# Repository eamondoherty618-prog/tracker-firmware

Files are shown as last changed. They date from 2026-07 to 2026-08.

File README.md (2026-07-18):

# 123 Mobile Track

Firmware, recovery tools, and deployment helpers for the tracker hardware
behind `123 Mobile Track`.

Current firmware: `v0.11.1`

## Start here

- [Build one tracker](docs/build-one-tracker.md)
- [Project map](docs/project-map.md)
- [Hardware wiring](docs/hardware-wiring.md)
- [Deployment guide](DEPLOYMENT.md)

## What is in this repo

| Path | What it is |
|---|---|
| `src/`, `include/`, `platformio.ini` | Tracker firmware. |
| `flash_new_tracker.sh` | Flash a brand-new board over USB and log its ID. |
| `make_sd_card.sh` | Build a field-recovery microSD card. |
| `deploy_firmware.sh` | Build and publish an OTA firmware release. |
| `fleet_inventory.csv` | Flash log for boards that have been provisioned. |
| `hardware/obd_tracker_carrier_v1/` | KiCad carrier-board files, BOM, placement file, and mechanical references. |
| `docs/` | Plain-English build guide, diagrams, wiring, and system overview. |

## Quick build and flash

```sh
pio run
pio run -t upload
./flash_new_tracker.sh
./make_sd_card.sh /Volumes/YOURCARD
```

## How the system fits together

1. The tracker boots on a `LilyGo T-SIM7000G`.
2. It reads GPS and optional add-ons like CAN/OBD2 or the impact sensor.
3. It sends telemetry to `123mobiletrack.com`.
4. The app and dashboard show the live vehicle state.
5. OTA releases are published from this repo and pulled by the trackers on
   their next check-in.

If you need the wiring details or the install order, start with the build guide
above.

## Repo hygiene

Tracked files should be firmware, deployment scripts, docs, and hardware source
files. Generated outputs, local KiCad session files, zip packages, telemetry
logs, PlatformIO builds, and unrelated shop/design files are ignored.

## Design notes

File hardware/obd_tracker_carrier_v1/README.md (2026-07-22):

# OBD Tracker Carrier Board v1

This package is a v1 KiCad-oriented carrier design for the proven LilyGo
T-SIM7000G + CAN + ADXL375 vehicle tracker architecture.

## Architecture Decision

Use **Option A** for v1: a carrier board for the proven LilyGo T-SIM7000G module.
The LilyGo already integrates the ESP32-WROVER, SIM7000G, USB flashing, SIM,
GNSS/LTE RF, battery charging, and antennas. Keeping it as a replaceable module
cuts RF/layout risk and small-batch cost. A fully native ESP32/SIM7000G board is
the right v2 only after fleet field data proves the enclosure, power section,
and harness approach.

## Board Geometry

- Board: **88.0 x 40.0 mm**, 1.6 mm FR-4. The KiCad source is a 2-layer v1 scaffold; a 4-layer production finalization is recommended for better EMI and thermal margin.
- Mounting holes: M2.5 clearance, 2.7 mm drill, 5.6 mm copper keepout.
- Hole centers:
  - H1: (4.0, 4.0) mm
  - H2: (84.0, 4.0) mm
  - H3: (84.0, 36.0) mm
  - H4: (4.0, 36.0) mm
- LilyGo module envelope: 66.0 x 27.0 mm at lower-left coordinate (18.0, 6.5) mm.
- Optional bottom 18650 holder envelope: 76.0 x 21.0 mm at lower-left coordinate (8.0, 9.5) mm.

The DXF contains the exact outline, hole centers, LilyGo envelope, and 18650
alternate footprint. The STEP file is a simplified board envelope for enclosure
blocking; use the DXF for exact hole cutouts.

## Functional Nets

- OBD2 input: J1 pin 1 = OBD16 +12V, pin 2 = OBD4 GND, pin 3 = OBD6 CAN-H, pin 4 = OBD14 CAN-L.
- CAN transceiver: TJA1051T/3 or equivalent, TXD -> GPIO32, RXD -> GPIO33, VCC = 5V, VIO = 3.3V.
- ADXL375: SDA -> GPIO21, SCL -> GPIO22, INT1 -> GPIO34, CS high, SDO low for address 0x53.
- Vehicle ADC: protected VIN through 100k/20k divider and 100nF filter to GPIO35.
- Battery ADC: VBAT through 1M/1M divider and 100nF filter to GPIO36.
- Status LED: GPIO23 active high, optional.
- Reserved LilyGo pins: GPIO26/27 modem UART and GPIO2/13/14/15 SD remain unconnected.

## Power Section

The v1 power path is:

`OBD +12V -> F1 resettable fuse -> D2 SMBJ33A TVS -> D1 5A reverse Schottky -> TPS54360 60V buck -> +5V`

The +5V rail feeds the LilyGo VIN/charger path and the 5V CAN transceiver. The
carrier uses the LilyGo's onboard 3.3V regulator and charge circuit. Battery
support is either J2 JST-PH LiPo or BT1 bottom-side 18650 holder, populated per
build, routed to the LilyGo battery/charger pins.

## Build Notes

- DNP R10/JP1 for normal vehicle installs. Only populate 120 ohm termination for bench setups or isolated test harnesses.
- L2 CAN common-mode choke is optional. Populate a CAN choke or 0-ohm bypass links after EMI testing.
- The generated routing scaffold uses bottom-layer orthogonal routes for bottom-side SMD circuitry, including CAN, TPS54360 support nets, ADXL375 I2C/INT, and ADC dividers.
- Use short, twisted OBD harness conductors for CAN-H/CAN-L and keep the harness shield/return strategy consistent with the enclosure.
- Place the ADXL375 side of the board against a rigid standoff area; avoid foam tape directly under the accelerometer if impact fidelity matters.
- Verify the exact LilyGo T-SIM7000G board revision and header geometry before fab. This reference uses the user-supplied 66 x 27 mm target envelope.
- For the lowest-height build, DNP BT1 and use a flat LiPo pouch via J2.

## Files

- `obd_tracker_carrier_v1.kicad_pro` - KiCad project settings and net classes.
- `obd_tracker_carrier_v1.kicad_pcb` - PCB outline, footprints, placement, pad nets, and baseline routing scaffold.
- `obd_tracker_carrier_v1.kicad_sch` - top-level schematic notes in KiCad format.
- `obd_tracker_carrier_v1_legacy.sch` - legacy KiCad schematic notes fallback.
- `bom/obd_tracker_carrier_v1_bom.csv` - BOM with suggested MPNs and LCSC/JLCPCB fields to verify at order time.
- `bom/obd_tracker_carrier_v1_netlist.csv` - readable netlist.
- `fab/obd_tracker_carrier_v1_placement.csv` - placement/mechanical coordinate table.
- `fab/obd_tracker_carrier_v1_stats.rpt` - KiCad-generated board statistics, created by the validation/export pass.
- `fab/obd_tracker_carrier_v1_erc.rpt` - KiCad schematic ERC report, created by the validation/export pass.
- `fab/VALIDATION.md` - validation commands and DRC limitation note.
- `mechanical/obd_tracker_carrier_v1_outline.dxf` - exact 2D board outline/hole/envelope DXF.
- `mechanical/obd_tracker_carrier_v1_board_reference.step` - simplified board envelope STEP.
- `mechanical/obd_tracker_carrier_v1_kicad_board.step` - KiCad-generated board-only STEP, created by the validation/export pass.
- `mechanical/kicad_dxf/` - KiCad-generated DXF exports for Edge.Cuts, Dwgs.User, and B.Fab.

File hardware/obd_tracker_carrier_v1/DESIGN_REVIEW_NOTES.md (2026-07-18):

# Design Review Notes

## Automotive Robustness

- The regulator is intentionally a 60V-class TPS54360 design instead of a cheaper
  24-28V buck module. This gives real headroom for load-dump-like pulses when
  paired with the fuse and SMBJ33A TVS.
- A Schottky reverse-protection diode is used for v1 simplicity and low sourcing
  risk. If bench thermal testing shows too much dissipation during long cellular
  upload bursts, replace D1 with an automotive high-side ideal-diode PFET circuit.
- The v1 buck should be validated with an electronic load using at least 2A pulses
  on +5V and with cranking sag profiles. The Li-ion backup should bridge crank
  intervals where the 5V buck falls out of regulation.

## Layout Risks To Verify In KiCad

- Run KiCad DRC after binding the exact vendor footprints.
- Review the TPS54360 compensation and switching loop against the TI datasheet.
- Keep the buck hot loop small: U2 VIN/GND, D3, and input capacitors should be
  tightened during final layout pass.
- Confirm the LilyGo module's USB-C remains accessible through the enclosure
  service opening or removable lid.
- Confirm ADXL375 orientation against firmware before using axis data for anything
  beyond magnitude-based impact detection.

## Fabrication Defaults

- KiCad source is a 2-layer v1 scaffold so it opens cleanly in KiCad 10. For
  production, convert to 4 layers: F.Cu signal/power, In1 GND plane, In2 +5V/VBAT
  pours, B.Cu signal/power.
- 1 oz outer copper is acceptable for a bench v1, but 2 oz outer copper improves reverse
  diode and buck thermal margin.
- ENIG finish preferred for corrosion resistance in a sealed but vehicle-mounted enclosure.

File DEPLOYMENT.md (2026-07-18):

# Deploying Trackers

Use this guide when you are setting up a new tracker, recovering a tracker in
the field, or wiring optional add-on hardware.

For a printable start-to-finish shop guide with diagrams, start with
[Build one tracker](docs/build-one-tracker.md).

If you just want the wiring and pinout, start with
[Hardware wiring](docs/hardware-wiring.md). If you want the overall system
flow, start with [Project map](docs/project-map.md).

## 1. Bench flash a new board

Use the factory image for every brand-new board.

```sh
./flash_new_tracker.sh
```

What happens:

- The board gets the same generic factory firmware.
- It names itself from the last six hex digits of its efuse MAC.
- The ID is logged to `fleet_inventory.csv`.
- The tracker advertises over BLE so the mobile app can claim it.

After flashing:

- Unplug and replug the board once.
- Put the printed ID on the case.
- Insert the SIM and power it in the vehicle.

## 2. Adopt it in the app

In the mobile app:

1. Open `Devices`.
2. Tap `Add Device`.
3. Claim the tracker that matches the label on the case.
4. Assign it to a vehicle.

After adoption:

- The tracker stops advertising continuously.
- It only advertises while the vehicle is on a trip.
- The dashboard starts showing live state for that vehicle.

## 3. Recover a unit with microSD

If the board is already running firmware `>= v0.10.5`, use the recovery card.

```sh
./make_sd_card.sh /Volumes/YOURCARD
```

Then:

1. Eject the card.
2. Insert it into the tracker.
3. Power-cycle the tracker.

The tracker checks the card at boot, verifies the MD5, flashes the new image,
and reboots. Identity in NVS is preserved, so the unit keeps its existing ID.

## 4. Publish an OTA release

```sh
./deploy_firmware.sh
```

This builds the firmware, uploads the binary to the OTA store, and updates the
release metadata. Devices pick it up on the next check-in.

## 5. Optional add-on hardware

See [Hardware wiring](docs/hardware-wiring.md) for the exact pins and safety
notes.

Short version:

- CAN / OBD2 uses `GPIO 32` and `GPIO 33`.
- The accelerometer uses I2C on `GPIO 21` and `GPIO 22`.
- `GPIO 34` is reserved for the accelerometer interrupt line.

## 6. Batch checklist

- [ ] Boards, SIMs, cases, labels
- [ ] One factory flash per new board
- [ ] `fleet_inventory.csv` updated
- [ ] SIMs inserted and active
- [ ] Vehicle install verified on the map
- [ ] Optional CAN / accelerometer wiring checked against the wiring doc

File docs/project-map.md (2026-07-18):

# Project Map

This repository is the firmware and deployment side of `123 Mobile Track`.
It does not contain the full web app source. The live dashboard and API are
hosted at `123mobiletrack.com`, and the firmware talks to that backend over
cellular.

## One-minute overview

System flow

## What lives where

| Piece | Where it lives | What it does |
|---|---|---|
| Firmware | `src/`, `include/`, `platformio.ini` | Runs on the tracker, reads sensors, talks to the modem, and posts telemetry. |
| Hardware carrier | `hardware/obd_tracker_carrier_v1/` | KiCad carrier-board design, BOM, placement file, and mechanical references. |
| App / dashboard | Separate app repo + `123mobiletrack.com` | Shows the map, vehicles, drivers, alerts, and device pages. |
| Telemetry backend | `123mobiletrack.com/api/fleet/*` | Receives tracker posts, serves OTA metadata, and drives device state. |
| OTA release store | Netlify Blobs via `deploy_firmware.sh` | Holds the current `.bin` plus version metadata. |
| Factory flash / recovery | `flash_new_tracker.sh`, `make_sd_card.sh` | Brings up a new board or field-recovers a board that cannot be reached over USB. |

## How the pieces talk to each other

1. The tracker boots, self-identifies, and reads GPS plus any optional add-on
   hardware that is present.
2. It sends telemetry to `123mobiletrack.com`.
3. The backend feeds the dashboard and app with live vehicle state.
4. The mobile app claims unadopted trackers over BLE.
5. Firmware releases are uploaded from this repo to the OTA store, then picked
   up by trackers on their next check-in.

## What this repo is for

- Building and flashing the tracker firmware.
- Keeping the carrier-board source and manufacturing references together.
- Publishing OTA releases.
- Re-flashing trackers in the field with microSD recovery cards.
- Documenting the tracker wiring and install process.

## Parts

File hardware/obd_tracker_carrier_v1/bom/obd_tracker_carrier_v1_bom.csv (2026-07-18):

Reference | Description | Manufacturer_Part | LCSC_JLCPCB | Qty | Notes
J1 | OBD2 harness connector, 4 pos locking or screw terminal | Molex Micro-Fit 3.0 43045-0400 preferred; KF128-2.54-4P alt | KF128 alt C474922; Micro-Fit verify/consign | 1 | Populate one connector style. Pin order: 12V, GND, CANH, CANL.
F1 | Resettable fuse, 1812, 30V, hold 2.0A | LUTE 1812L200/30GRT | C49326271 | 1 | Place before TVS so reverse/transient faults are current-limited.
D1 | Reverse-polarity series Schottky, 5A, 60V | GOODWORK SS56 or equivalent | C2848693 | 1 | Schottky v1 for simplicity. PFET ideal-diode option can replace after thermal testing.
D2 | Automotive input TVS, 600W, 33V standoff | Jingdao SMBJ33A or automotive-qualified equivalent | C353366 | 1 | Choose working voltage above jump-start/normal operation and below buck abs-max clamp margin.
U2 | 60V buck regulator, 3.5A switch, SO-PowerPAD-8 | TI TPS54360DDAR | C44377 | 1 | Chosen over 28V bucks for load-dump headroom.
L1 | Shielded power inductor, 15uH, >=4A, low DCR | Bourns SRN6045/7447719150-class | verify footprint | 1 | Final value should be checked against TPS54360 Webench/datasheet equations.
D3 | Buck catch Schottky, 5A, 60V | GOODWORK SS56 or equivalent | C2848693 | 1 | Required because TPS54360 is asynchronous.
C1,C2 | Input ceramic capacitor, 10uF, 50V, X7R | 0805/1206 automotive grade preferred | JLC generic | 2 | Use two in parallel near VIN/GND of buck.
C3,C4 | Output capacitor, 47uF, 10V, X7R/polymer | 1206 ceramic or polymer low ESR | JLC generic | 2 | Size output ripple for SIM7000G TX bursts.
C5,C6,C7,C8,C9,C10,C11,C12 | Decoupling/filter capacitors | 0603/0805 X7R | JLC generic | 8 | Values are labelled in PCB footprints and BOM notes.
R1 | Vehicle ADC top resistor, 100k 1% | 0603 | JLC generic | 1 | With R2 scales 18V to about 3.0V.
R2 | Vehicle ADC bottom resistor, 20.0k 1% | 0603 | JLC generic | 1 | RC filter cap to ground at ADC node.
R3,R4 | Battery ADC divider, 1.0M 1% | 0603 | JLC generic | 2 | 4.2V battery reads about 2.1V at GPIO36.
R5 | Buck feedback top, 52.3k 1% | 0603 | JLC generic | 1 | 5.0V target with TPS54360 0.8V reference.
R6 | Buck feedback bottom, 10.0k 1% | 0603 | JLC generic | 1 | Feedback divider bottom.
R7 | Buck EN top, 200k 1% | 0603 | JLC generic | 1 | Approx 6V UVLO threshold with R8.
R8 | Buck EN bottom, 49.9k 1% | 0603 | JLC generic | 1 | Approx 6V UVLO threshold with R7.
R9 | Buck RT resistor, 200k | 0603 | JLC generic | 1 | Check final switching frequency/noise tradeoff during regulator validation.
U3 | 5V high-speed CAN transceiver with 3.3V IO | NXP TJA1051T/3/1J or MCP2562FD VIO variant | C38695 | 1 | TXD GPIO32, RXD GPIO33. S/STB tied normal mode.
D4 | CAN bus ESD protector | Nexperia PESD1CAN,215 | C15771 | 1 | Place between connector and choke/transceiver.
L2 | CAN common-mode choke, optional | ACT45B/51MC-class | DNP or verify | 0/1 | DNP by default or replace with 0R links for v1 testing.
R10,JP1 | Optional CAN termination | 120R 0603 plus solder jumper | JLC generic | DNP | Do not populate for vehicle bus tapping.
U4 | High-g accelerometer, LGA-14 | Analog Devices ADXL375BCCZ-RL7 | C481898 | 1 | Placed near H2 for good impact coupling.
R11,R12 | I2C pull-ups, 4.7k | 0603 | JLC generic | 2 | Pull to LilyGo 3.3V rail.
R13 | INT1 pulldown, 100k | 0603 | JLC generic | 1 | GPIO34 has no internal pull resistor.
D5,R15 | Status LED and 1k series resistor | 0603/0805 LED | JLC generic | 1 set | GPIO23 active high, optional.
J2 | LiPo battery connector, JST-PH 2.0 2-pin | JST S2B-PH-SM4-TB(LF)(SN) or B2B-PH-K-S | C295747 SMT or C131337 THT | 1 | Populate for slim pouch build; route to LilyGo battery/charger pins.
BT1 | Single 18650 holder footprint | Keystone 1042/1043-class or slim 1S holder | usually hand-assembly, verify | DNP/1 | Bottom-side alternate. Not for the lowest-height build.
J3A,J3B | T-SIM7000G low-profile header/solder rail | 2.54mm low-profile receptacle or direct solder pads | JLC generic/hand assembly | 2 | Exact LilyGo board revision and header positions must be measured before fab.

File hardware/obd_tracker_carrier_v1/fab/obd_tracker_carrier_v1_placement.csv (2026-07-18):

Reference | X_mm | Y_mm | Side | Notes
J1 | 7 | 20 | Top | OBD harness entry side
J2 | 10 | 32.5 | Top | JST-PH LiPo, DNP if 18650 build
BT1 | 46 | 20 | Bottom | 18650 holder envelope, DNP in slim build
J3A | 19.2 | 7.3 | Top | T-SIM left/header rail, exact rev verify
J3B | 82.8 | 7.3 | Top | T-SIM right/header rail, exact rev verify
U2 | 38.5 | 7.7 | Bottom | Buck regulator
U3 | 60.5 | 33 | Bottom | CAN transceiver
U4 | 75.5 | 8 | Bottom | ADXL375, near H2 rigid corner
L2 | 22.5 | 25 | Bottom | Optional CAN common-mode choke
D2 | 15.5 | 14.3 | Bottom | Input TVS near connector
H1 | 4 | 4 | Mechanical | M2.5 2.7mm drill
H2 | 84 | 4 | Mechanical | M2.5 2.7mm drill
H3 | 84 | 36 | Mechanical | M2.5 2.7mm drill
H4 | 4 | 36 | Mechanical | M2.5 2.7mm drill

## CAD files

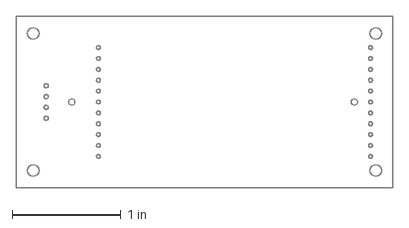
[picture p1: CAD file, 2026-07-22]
hardware/obd_tracker_carrier_v1/mechanical/kicad_dxf/obd_tracker_carrier_v1-Edge_Cuts.dxf
3.46 x 1.57 in

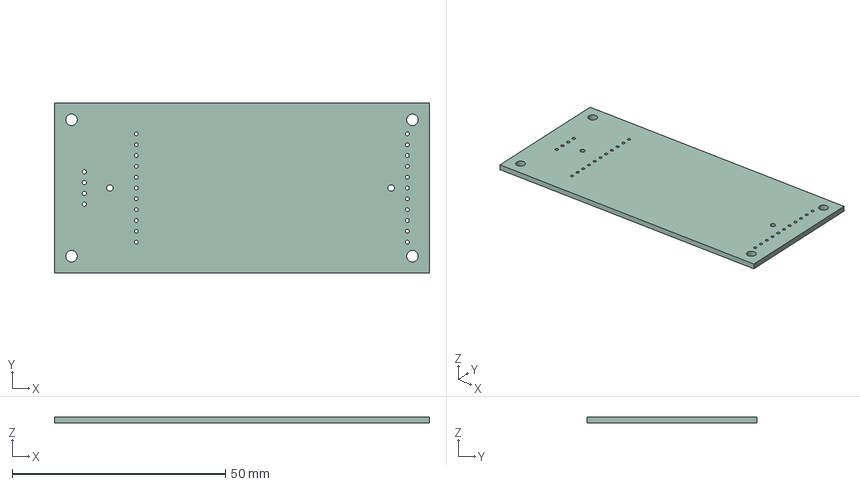
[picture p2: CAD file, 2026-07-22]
hardware/obd_tracker_carrier_v1/mechanical/obd_tracker_carrier_v1_kicad_board.step
88.0 x 40.0 x 1.51 mm

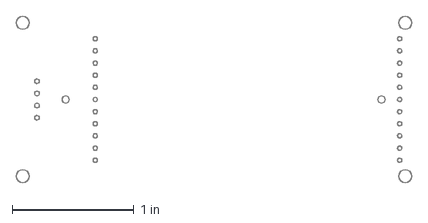
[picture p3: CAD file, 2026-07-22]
hardware/obd_tracker_carrier_v1/mechanical/kicad_dxf/obd_tracker_carrier_v1-F_Fab.dxf
3.26 x 1.37 in

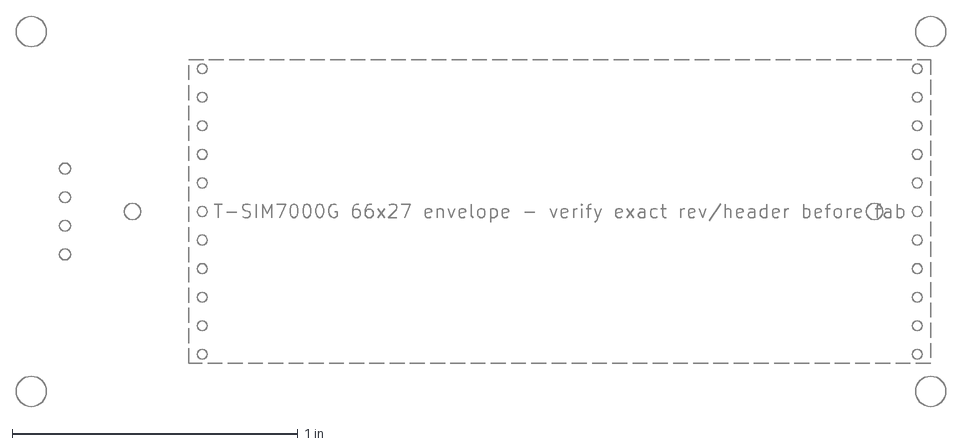
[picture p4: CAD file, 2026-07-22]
hardware/obd_tracker_carrier_v1/mechanical/kicad_dxf/obd_tracker_carrier_v1-User_Drawings.dxf
3.26 x 1.37 in

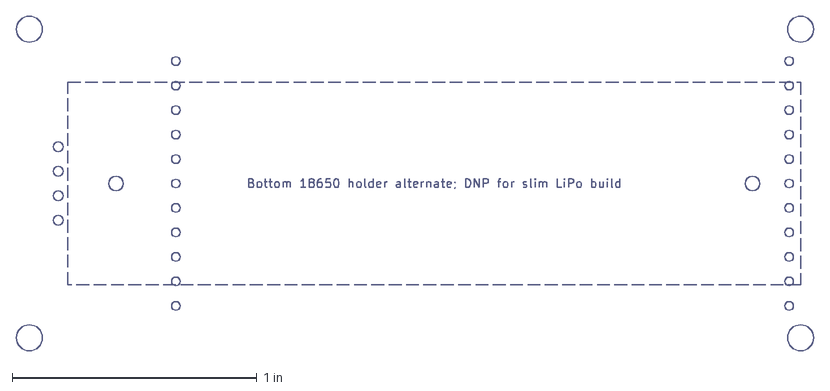
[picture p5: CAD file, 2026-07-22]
hardware/obd_tracker_carrier_v1/mechanical/kicad_dxf/obd_tracker_carrier_v1-B_Fab.dxf
3.26 x 1.37 in

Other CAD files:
hardware/obd_tracker_carrier_v1/mechanical/obd_tracker_carrier_v1_board_reference.step
hardware/obd_tracker_carrier_v1/mechanical/obd_tracker_carrier_v1_outline.dxf

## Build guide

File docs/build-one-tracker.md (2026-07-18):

# Build One Tracker

This is the start-to-finish shop guide for one complete tracker.

## What you are building

System flow

The tracker lives in the vehicle, reads GPS and optional add-on hardware, sends
telemetry through the 1NCE SIM, and shows up in the dashboard/app.

## Parts

| Part | Why it is there |
|---|---|
| LilyGo T-SIM7000G | Main tracker board: ESP32, modem, SIM, GPS, USB flash, battery charger. |
| 1NCE SIM | Cellular data path. |
| GPS/LTE antennas | GNSS fix and cellular connection. |
| 12V to 5V buck | Vehicle power to tracker VIN. |
| LiPo or 18650 backup | Buffers modem current bursts and crank dips. |
| Optional CAN carrier / module | Reads OBD2 CAN data. |
| Optional ADXL375 | Impact/tamper sensor. |
| Case, labels, harness | Vehicle install hardware. |

## Wiring

Tracker wiring

Core tracker wiring:

| Function | Connection |
|---|---|
| Vehicle power | 12V input to protected 5V buck, then 5V to tracker VIN. |
| Ground | Vehicle ground to buck ground and tracker ground. |
| Modem UART | Already wired on the LilyGo board. |
| microSD recovery | Already wired on the LilyGo board. |
| GPS/LTE | Plug antennas into the LilyGo antenna connectors. |

Optional OBD2 wiring:

OBD2 pinout

| OBD2 pin | Signal | Connect to |
|---|---|---|
| `4` | Ground | CAN module `G` |
| `6` | CAN-H | CAN module `H` |
| `14` | CAN-L | CAN module `L` |
| `16` | Battery 12V | Do not connect to the CAN board |

Optional add-on pins:

| Add-on | Tracker pins |
|---|---|
| CAN TX/RX | `GPIO 32` TX, `GPIO 33` RX |
| ADXL375 I2C | `GPIO 21` SDA, `GPIO 22` SCL |
| ADXL375 INT1 | `GPIO 34`, reserved |

## Flash and label

Install flow

1. Plug in one tracker over USB.
2. Run `./flash_new_tracker.sh`.
3. Write the printed `tracker-xxxxxx` ID on the case.
4. Insert the SIM.
5. Power-cycle the tracker once after flashing.

## Install in the vehicle

1. Mount the tracker where the antennas can work.
2. Connect vehicle power through the 12V to 5V buck.
3. Connect the backup battery.
4. If using CAN, verify OBD2 pin `6`, `14`, and `4` before plugging in.
5. Power the tracker before plugging into OBD2.
6. Plug in with ignition off.

## Adopt in the app

1. Open `Devices`.
2. Tap `Add Device`.
3. Pick the tracker ID that matches the label.
4. Assign it to the vehicle.
5. Confirm the vehicle shows up on the dashboard map.

## Recovery

Use this when a tracker is already in the field and needs firmware without a
laptop.

```sh
./make_sd_card.sh /Volumes/YOURCARD
```

Then insert the card into the tracker and power-cycle it. The tracker flashes
the image, keeps its identity, and comes back as the same device.

## Quick checks

| Symptom | First thing to check |
|---|---|
| No telemetry | SIM active, antennas connected, tracker has power. |
| Shows offline | Wait for next heartbeat, then check cellular signal and power. |
| Brownout/reset behavior | Backup battery connected and healthy. |
| CAN not present | Confirm pins `6`, `14`, `4`, remove 120R termination, use listen-only first. |
| App cannot find tracker | Tracker is unadopted, nearby, and BLE advertising. |

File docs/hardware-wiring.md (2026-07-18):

# Hardware Wiring

This page is the quick reference for the tracker hardware that actually lives
in this repo.

The KiCad carrier-board source is in `hardware/obd_tracker_carrier_v1/`.
Generated zip packages and KiCad lock/session files stay out of Git.

Tracker wiring

## Core board

The main board is a `LilyGo T-SIM7000G`.

| Function | Pins |
|---|---|
| Modem UART | `GPIO 26` RX, `GPIO 27` TX |
| Modem power key | `GPIO 4` |
| microSD SPI | `GPIO 2` MISO, `GPIO 13` CS, `GPIO 14` SCLK, `GPIO 15` MOSI |
| CAN / OBD2 add-on | `GPIO 32` TX, `GPIO 33` RX |
| ADXL375 accelerometer | `GPIO 21` SDA, `GPIO 22` SCL, `GPIO 34` INT1 |

## CAN / OBD2 add-on

The CAN module is passive unless the firmware detects and uses it.

OBD2 pinout

| CAN module terminal | Connect to |
|---|---|
| `H` | OBD2 pin `6` |
| `L` | OBD2 pin `14` |
| `G` | OBD2 pin `4` |
| `HV` | Leave empty |

| Grove lead | Connect to |
|---|---|
| yellow (CAN TX) | `GPIO 32` |
| white (CAN RX) | `GPIO 33` |
| black (GND) | GND |
| red (5V) | tracker `VIN 5V` |

Important:

- Do not power the CAN board from OBD2 pin `16`.
- Remove the `120 ohm` terminator from the CAN board.
- First live vehicle test should start in listen-only mode.
- Plug the unit in with ignition off.

## ADXL375 accelerometer

| Breakout pin | Connect to |
|---|---|
| `VCC` / `VS` | `3V3` |
| `GND` | GND |
| `CS` | `3V3` |
| `SDA` | `GPIO 21` |
| `SCL` | `GPIO 22` |
| `INT1` | `GPIO 34` reserved for wake in a future revision |

Important:

- This board is `3.3V` only.
- If the accelerometer is wired backwards from the silkscreen, trust the scan
  result in the bench debug build, not the label.

## Data flow

| Event | What happens |
|---|---|
| Tracker boots | Self-provisions an identity if needed, then starts telemetry. |
| Tracker is moving | GPS motion shortens the heartbeat interval. |
| Tracker is parked | Heartbeat slows down to save data and power. |
| OBD2 is present | Firmware polls RPM, speed, coolant, throttle, VIN, and DTCs. |
| Impact sensor is present | Firmware records high-g events and reports peaks. |

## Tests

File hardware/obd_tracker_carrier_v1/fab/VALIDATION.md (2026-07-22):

# Validation

Validated on KiCad CLI 10.0.3 from `/Applications/KiCad/KiCad.app/Contents/MacOS/kicad-cli`.

- `pcb upgrade --force` succeeded on `obd_tracker_carrier_v1.kicad_pcb`.
- `pcb export stats` succeeded and wrote `obd_tracker_carrier_v1_stats.rpt`.
- `pcb export pos` succeeded and wrote `obd_tracker_carrier_v1_kicad_pos.csv`.
- `pcb export dxf` succeeded and wrote the files in `mechanical/kicad_dxf/`.
- `pcb export step --board-only --no-components` succeeded and wrote `mechanical/obd_tracker_carrier_v1_kicad_board.step`.
- `sch erc` succeeded with 0 violations and wrote `obd_tracker_carrier_v1_erc.rpt`.
- Custom generated-file checks confirmed 0 wrong-layer SMD route contacts across
  83 segment-to-pad contacts.
- TPS54360 pad nets checked after correction: pin 5 = `BUCK_FB`, pin 7 = `GND`.
- ADXL375 pad nets checked after correction: pin 1/3/6/7 = `+3V3`, pin 8 =
  `ACCEL_INT1_GPIO34`, pin 12 = `GND`, pin 13 = `I2C_SDA_GPIO21`, pin 14 =
  `I2C_SCL_GPIO22`.

`pcb drc` loads the board but aborts in this local KiCad 10.0.3 CLI run before
writing a report. Treat this package as a v1 reference layout/scaffold and run a
fresh PCB DRC in the KiCad GUI after binding exact vendor footprints, tightening
the buck regulator layout, and completing final routing before fabrication.

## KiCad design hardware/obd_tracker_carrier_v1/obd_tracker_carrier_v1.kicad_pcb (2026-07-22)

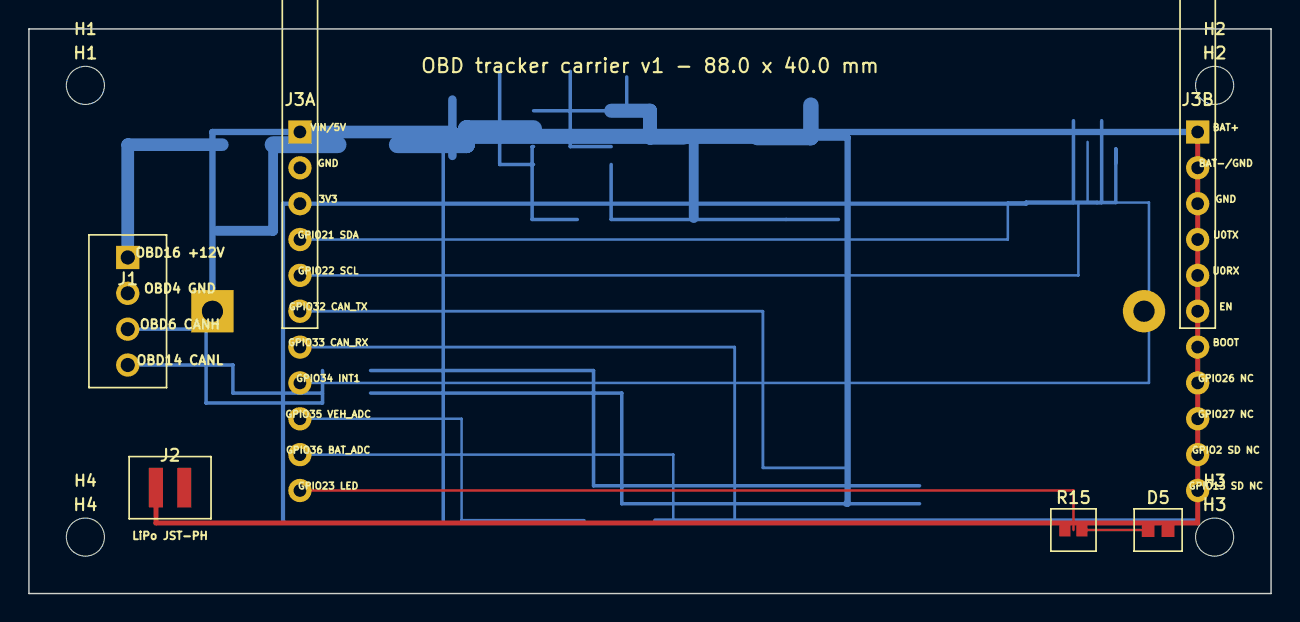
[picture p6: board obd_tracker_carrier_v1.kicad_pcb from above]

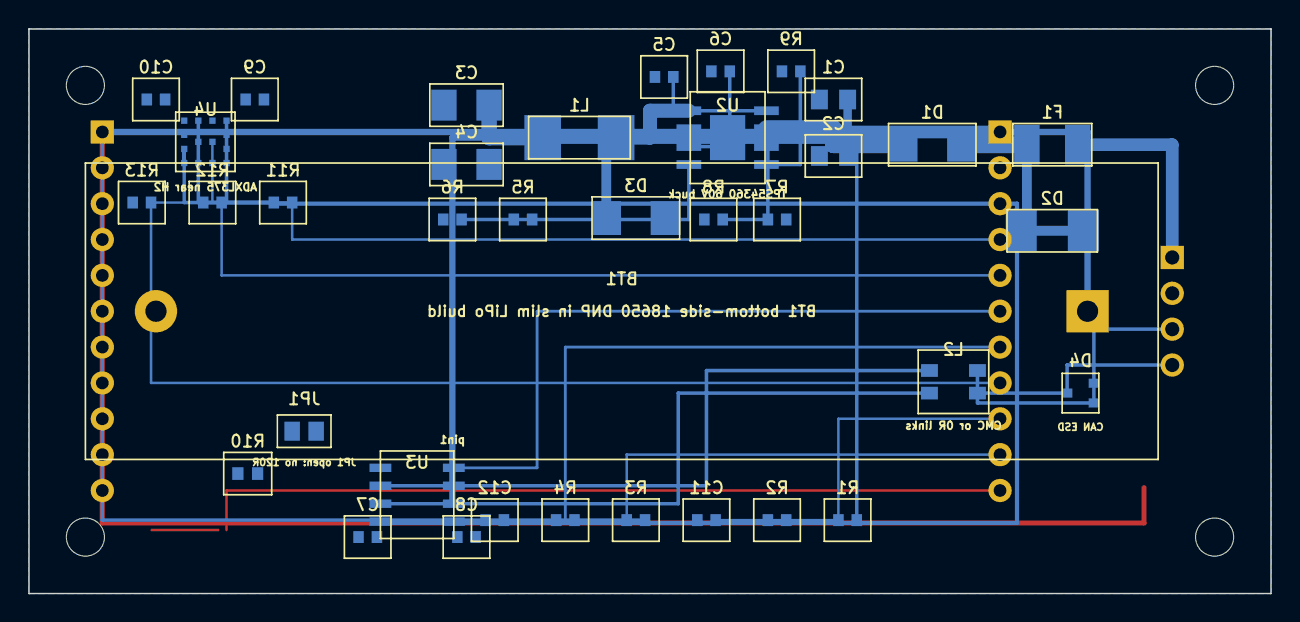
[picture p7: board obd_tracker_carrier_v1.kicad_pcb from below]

Board: 2 copper layers, 88.0 x 40.0 mm, 47 parts (37 on the bottom side), 27 nets.

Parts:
BT1: Single 18650 holder alternate footprint; BatteryHolder_18650
C1, C2: 10uF 50V input cap; SMD_2Pad
C3, C4: 47uF 10V output cap; SMD_2Pad
C5: 100nF bootstrap; SMD_2Pad
C6: Compensation cap placeholder; SMD_2Pad
C7: 100nF CAN VCC; SMD_2Pad
C8: 100nF CAN VIO; SMD_2Pad
C9: 100nF accel decoupling; SMD_2Pad
C10: 1uF accel decoupling; SMD_2Pad
C11: 100nF vehicle ADC filter; SMD_2Pad
C12: 100nF battery ADC filter; SMD_2Pad
D1: B560C/SS56 reverse Schottky; SMD_2Pad
D2: SMBJ33A load-dump TVS; SMD_2Pad
D3: B560C buck catch diode; SMD_2Pad
D4: CAN ESD protector, SOT-23; SOT-23
D5: Green status LED; SMD_2Pad
F1: 2A resettable fuse, 1812; SMD_2Pad
H1, H2, H3, H4: M2.5 mounting hole; MountingHole_M2.5
J1: OBD2 harness 12V/GND/CANH/CANL; Harness_4P_2.54
J2: JST-PH-2 LiPo, populate instead of BT1; JST_PH_S2B-PH-SM4-TB
J3A, J3B: T-SIM7000G low profile header rail; TSIM_Header_Rail
JP1: Optional CAN termination solder jumper, open by d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; SolderJumper_2_Open
L1: 15uH shielded inductor >=4A; SMD_2Pad
L2: CAN common-mode choke DNP/0R bypass; CommonModeChoke_CAN
R1: 100k vehicle ADC top; SMD_2Pad
R2: 20.0k vehicle ADC bottom; SMD_2Pad
R3: 1.0M battery ADC top; SMD_2Pad
R4: 1.0M battery ADC bottom; SMD_2Pad
R5: 52.3k 1% FB top; SMD_2Pad
R6: 10.0k 1% FB bottom; SMD_2Pad
R7: 200k EN top; SMD_2Pad
R8: 49.9k EN bottom; SMD_2Pad
R9: 200k RT; SMD_2Pad
R10: 120R CAN termination DNP; SMD_2Pad
R11: 4.7k I2C SDA pull-up; SMD_2Pad
R12: 4.7k I2C SCL pull-up; SMD_2Pad
R13: 100k INT1 pulldown; SMD_2Pad
R15: 1k LED series; SMD_2Pad
U2: TPS54360DDAR 12V-to-5V buck; TI_SO-PowerPAD-8
U3: TJA1051T/3 5V CAN transceiver; SOIC-8_3.9x4.9mm_P1.27mm
U4: ADXL375BCCZ-RL7; ADXL375_LGA-14

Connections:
+3V3: C8.1, C9.1, C10.1, J3A.3 (3V3), R11.2, R12.2, U3.5, U4.1, U4.3, U4.6, U4.7
+5V: C3.1, C4.1, C7.1, J3A.1 (VIN/5V), L1.2, R5.1, U3.3
ACCEL_INT1_GPIO34: J3A.8 (GPIO34 INT1), R13.1, U4.8
BUCK_BOOT: C5.1, U2.1
BUCK_COMP: C6.1, U2.6
BUCK_EN: R7.2, R8.1, U2.3
BUCK_FB: R5.2, R6.1, U2.5
BUCK_RT: R9.1, U2.4
BUCK_SW: C5.2, D3.2, L1.1, U2.8
CANH: JP1.1, L2.3, U3.7
CANH_OBD: D4.1 (CANH), J1.3 (OBD6 CANH), L2.1
CANL: L2.4, R10.2, U3.6
CANL_OBD: D4.3 (CANL), J1.4 (OBD14 CANL), L2.2
CAN_RX_GPIO33: J3A.7 (GPIO33 CAN_RX), U3.4
CAN_TERM_H: JP1.2, R10.1
CAN_TX_GPIO32: J3A.6 (GPIO32 CAN_TX), U3.1
GND: BT1.2 (BAT-), C1.2, C2.2, C3.2, C4.2, C6.2, C7.2, C8.2, C9.2, C10.2, C11.2, C12.2, D2.2, D3.1, D4.2 (GND), D5.2, J1.2 (OBD4 GND), J2.2 (BAT-), J3A.2 (GND), J3B.2 (BAT-/GND), J3B.3 (GND), R2.2, R4.2, R6.2, R8.2, R9.2, R13.2, U2.7, U2.9, U3.2, U3.8, U4.2, U4.4, U4.5, U4.10, U4.12
I2C_SCL_GPIO22: J3A.5 (GPIO22 SCL), R12.1, U4.14
I2C_SDA_GPIO21: J3A.4 (GPIO21 SDA), R11.1, U4.13
LED_A: D5.1, R15.2
STATUS_LED_GPIO23: J3A.11 (GPIO23 LED), R15.1
VBAT: BT1.1 (BAT+), J2.1 (BAT+), J3B.1 (BAT+), R3.1
VBAT_SENSE_GPIO36: C12.1, J3A.10 (GPIO36 BAT_ADC), R3.2, R4.1
VEH_SENSE_GPIO35: C11.1, J3A.9 (GPIO35 VEH_ADC), R1.2, R2.1
VIN_FUSED: D1.1, D2.1, F1.2
VIN_OBD: F1.1, J1.1 (OBD16 +12V)
VIN_PROT: C1.1, C2.1, D1.2, R1.1, R7.1, U2.2

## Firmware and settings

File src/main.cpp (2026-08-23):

#include <Arduino.h>
#include <ArduinoJson.h>
#include <BLECharacteristic.h>
#include <BLEDevice.h>
#include <BLEServer.h>
#include <BLEUtils.h>
#include <MD5Builder.h>
#include <Preferences.h>
#include <SD.h>
#include <SPI.h>
#include <TinyGsmClient.h>
#include <Update.h>
#include <WiFi.h>

#include "tracker_config.h"
#include "can_obd2.h"
#include "accel_tamper.h"

// Fleet tracker GATT service — advertised continuously so the mobile app can
// discover and claim this tracker via Bluetooth without typing a device ID.
#define FLEET_BLE_SERVICE_UUID  "1230FACE-0001-4A7E-9C00-000000000001"
#define FLEET_BLE_DEVINFO_UUID  "1230FACE-0002-4A7E-9C00-000000000001"

namespace {

// LilyGo T-SIM7000G v1.x defaults.
constexpr int MODEM_TX = 27;
constexpr int MODEM_RX = 26;
constexpr int MODEM_PWRKEY = 4;
constexpr int MODEM_BAUD = 115200;

// Onboard microSD slot (SPI). Used only at boot to look for a firmware.bin to
// self-flash — the field-recovery path when a unit can't be reached over USB.
constexpr int SD_SCLK = 14;
constexpr int SD_MISO = 2;
constexpr int SD_MOSI = 15;
constexpr int SD_CS   = 13;

constexpr size_t QUEUE_DEPTH = 24;

HardwareSerial SerialAT(1);
TinyGsm modem(SerialAT);
TinyGsmClientSecure secureClient(modem, 0);

// Runtime credentials — populated from NVS if provisioned, otherwise fall back
// to the compile-time TRACKER_DEVICE_ID / TRACKER_API_KEY values.
String g_deviceId;
String g_apiKey;
bool g_provisioned = false;
// Adoption latch (NVS-persisted, server-driven): false until the server's
// telemetry response reports this device is assigned to a vehicle in some org.
// Unadopted boards advertise over BLE continuously so the app can claim them;
// adopted boards only advertise while on a trip (driver presence). Un-claiming
// the device in the app flips this back and the board becomes adoptable again.
bool g_adopted = false;

struct QueuedMessage {
  String body;
  uint32_t queuedAtMs = 0;
};

QueuedMessage queue[QUEUE_DEPTH];
size_t queueHead = 0;
size_t queueCount = 0;

uint32_t lastTelemetryMs = 0;
uint32_t lastPostSuccessMs = 0;  // watchdog: reset on every confirmed POST
constexpr uint32_t POST_WATCHDOG_MS = 90UL * 1000UL;   // 90s — recover fast from dead data sessions
uint8_t telemetryCycleCount = 0;
// Diagnostics surfaced in telemetry so we can see what happens mid-drive without a serial cable.
uint8_t g_consecutivePostFails = 0;   // resets on success
uint16_t g_watchdogCount = 0;         // times the POST watchdog power-cycled the modem
uint16_t g_forcedReconnects = 0;      // times GPRS was torn down after repeated post fails
uint32_t g_bootCount = 0;             // persisted across reboots (NVS) — detects brownout/crash resets
uint32_t lastSpeedSampleMs = 0;
float lastSpeedKph = NAN;
float g_crashReportG = 0;  // crash candidate peak awaiting inclusion in the next payload
uint32_t g_fastStreamUntilMs = 0;  // mechanic mode: 1s posting until this deadline
bool gpsEnabled = false;
bool gprsConnected = false;
uint32_t lastNetworkWaitMs = 0;
uint32_t gpsEnabledAtMs = 0;
uint32_t lastGnssStatusLogMs = 0;
bool lastGpsFix = false;
bool lastGpsQualityFix = false;
float lastKnownLat = NAN;
float lastKnownLon = NAN;
char lastKnownTimestamp[25] = "";
float lastKnownCourse = NAN;  // degrees from North, computed from consecutive fixes
float prevFixLat = NAN;       // lat of previous quality fix (for heading computation)
float prevFixLon = NAN;
uint32_t lastFixMs = 0;       // millis() when last quality fix was stored
// Stationary position lock — freeze reported position when parked to eliminate GPS drift.
uint32_t stationaryStartMs = 0;
float stationaryLat = NAN;
float stationaryLon = NAN;
constexpr uint32_t STATIONARY_LOCK_MS = 30000UL;  // lock after 30s stopped
constexpr float STATIONARY_SPEED_KPH = 2.0f;      // below this = stationary
uint32_t lastAgpsMs = 0;
uint32_t gpsFirstFixMs = 0;
bool ignitionOn = false;  // true when on a trip (GPS motion within the grace window)
uint32_t ignitionOffSinceMs = 0;  // millis() when ignition last went off (0 = on/unknown)
uint32_t lastMovingMs = 0;        // millis() of the last GPS reading at/above moving speed
// Smart-sleep: once the engine's been off this long, drop to a slow heartbeat. The
// heartbeat stays well under the app's 35-min offline cutoff, so the vehicle keeps
// showing "parked" (not "offline") while it sits, at ~5x less parked power/data.
constexpr uint32_t DEEP_PARK_AFTER_MS = 10UL * 60UL * 1000UL;
constexpr uint32_t PARKED_HEARTBEAT_MS = 10UL * 60UL * 1000UL;
uint16_t g_lastBattMv = 0;
BLECharacteristic* g_bleDevInfoChar = nullptr;

// Hardware loop watchdog — reboots the board if the main loop stops making progress
// (e.g. a blocking call like WiFi.scanNetworks() or a modem read hangs). The software
// recovery can't help a HUNG loop because it only runs when postJson() returns; this
// timer ISR fires independently and forces a reboot. (Field freeze: stopped posting
// mid-drive with watchdog_count=0, forced_reconnects=0, no reboot = loop was hung.)
hw_timer_t* g_loopWdt = nullptr;
volatile uint32_t g_loopBeat = 0;

// Hang breadcrumb — records the operation currently running in RTC memory (survives a
// software/watchdog reset). On the next boot we read what it was doing when it hung,
// plus the reset reason, and report both in telemetry to pinpoint the freeze source.
RTC_NOINIT_ATTR char g_breadcrumb[24];
RTC_NOINIT_ATTR uint32_t g_breadcrumbMagic;
char g_lastHangOp[24] = "";     // breadcrumb from before the last reset (reported once)
char g_lastBuiltMotion[12] = ""; // motion_state of the most recently built telemetry payload
// 1NCE UDP health: sends since the last HTTPS heartbeat, consecutive local
// send failures, the server's report of when a datagram last ARRIVED
// (udp_age_s; -2 = no report yet), and the HTTPS-only cooldown deadline.
uint32_t g_udpSentSinceHb = 0;
// Last time the server CONFIRMED hearing us (any successful HTTPS exchange).
// UDP can't update this — it's fire-and-forget. 0 = no contact since boot.
uint32_t g_lastServerContactMs = 0;
uint32_t g_udpFailStreak = 0;
long g_lastServerUdpAgeS = -2;
uint32_t g_udpDisabledUntilMs = 0;
const char* g_resetReason = ""; // why the board last reset (sw/panic/brownout/poweron)
// Breadcrumb + watchdog feed: every stage marker also feeds the loop watchdog,
// so legitimately-long sequential stages (setup's modem bring-up, slow cell
// attach after a crash reboot) don't trip the 180s ISR — while a genuinely
// hung stage stops dropping crumbs and still gets reset. Field bug: the
// watchdog armed at the top of setup() with no feed until loop() turned every
// slow attach into a reboot CHAIN, multiplying boot_count.
#define CRUMB(s) do { strncpy(g_breadcrumb, (s), sizeof(g_breadcrumb) - 1); g_breadcrumb[sizeof(g_breadcrumb) - 1] = 0; g_loopBeat++; } while (0)

void powerOnModem() {
  pinMode(MODEM_PWRKEY, OUTPUT);
  digitalWrite(MODEM_PWRKEY, HIGH);
  delay(100);
  digitalWrite(MODEM_PWRKEY, LOW);
  delay(1100);
  digitalWrite(MODEM_PWRKEY, HIGH);
  delay(3000);
}

// Forward declaration — defined later, but needed here to disable modem sleep
// the moment the modem first responds (both at boot and after a watchdog reset).
bool sendSimpleAt(const String& command, uint32_t timeoutMs);

bool waitForModem() {
  Serial.print("Waiting for modem");
  for (int attempt = 0; attempt < 20; attempt++) {
    if (modem.testAT(1000)) {
      Serial.println(" ok");
      // Disable all modem power-saving modes — the SIM7000G and 1NCE network
      // can negotiate PSM / UART sleep, making the modem unreachable mid-drive.
      sendSimpleAt("+CSCLK=0", 3000);   // disable UART sleep
      sendSimpleAt("+CPSMS=0", 3000);   // disable PSM (network power saving)
      return true;
    }
    Serial.print(".");
    delay(500);
  }
  Serial.println(" failed");
  return false;
}

void logAtCommand(const char* command, uint32_t timeoutMs = 3000) {
  while (SerialAT.available()) {
    SerialAT.read();
  }

  Serial.print("AT");
  Serial.println(command);
  SerialAT.print("AT");
  SerialAT.print(command);
  SerialAT.print("\r\n");

  const uint32_t deadline = millis() + timeoutMs;
  String line;
  while (millis() < deadline) {
    while (SerialAT.available()) {
      const char c = static_cast<char>(SerialAT.read());
      if (c == '\r') {
        continue;
      }
      if (c == '\n') {
        line.trim();
        if (line.length() > 0) {
          Serial.print("  ");
          Serial.println(line);
          if (line == "OK" || line == "ERROR") {
            return;
          }
        }
        line = "";
      } else {
        line += c;
      }
    }
    delay(5);
  }

  line.trim();
  if (line.length() > 0) {
    Serial.print("  ");
    Serial.println(line);
  }
  Serial.println("  <timeout>");
}

void drainSerialAt() {
  while (SerialAT.available()) {
    SerialAT.read();
  }
}

bool waitForLineContaining(const char* token, String& matchedLine, uint32_t timeoutMs) {
  const uint32_t deadline = millis() + timeoutMs;
  String line;
  while (millis() < deadline) {
    while (SerialAT.available()) {
      const char c = static_cast<char>(SerialAT.read());
      if (c == '\r') {
        continue;
      }
      if (c == '\n') {
        line.trim();
        if (line.length() > 0) {
          if (line.indexOf(token) >= 0) {
            matchedLine = line;
            return true;
          }
          line = "";
        }
      } else {
        line += c;
      }
    }
    delay(5);
  }
  matchedLine = "";
  return false;
}

bool waitForOk(uint32_t timeoutMs) {
  String matchedLine;
  return waitForLineContaining("OK", matchedLine, timeoutMs);
}

bool waitForPromptChar(char target, uint32_t timeoutMs) {
  const uint32_t deadline = millis() + timeoutMs;
  while (millis() < deadline) {
    while (SerialAT.available()) {
      const char c = static_cast<char>(SerialAT.read());
      if (c == target) {
        Serial.print("Prompt: ");
        Serial.println(target);
        return true;
      }
      if (c != '\r' && c != '\n') {
        Serial.print("Prompt saw: ");
        Serial.println(c);
      }
    }
    delay(5);
  }
  Serial.println("Prompt: <timeout>");
  return false;
}

bool waitForOkVerbose(uint32_t timeoutMs, const char* context) {
  const uint32_t deadline = millis() + timeoutMs;
  String line;
  while (millis() < deadline) {
    while (SerialAT.available()) {
      const char c = static_cast<char>(SerialAT.read());
      if (c == '\r') {
        continue;
      }
      if (c == '\n') {
        line.trim();
        if (line.length() > 0) {
          Serial.print(context);
          Serial.print(": ");
          Serial.println(line);
          if (line == "OK") {
            return true;
          }
          if (line == "ERROR") {
            return false;
          }
          line = "";
        }
      } else {
        line += c;
      }
    }
    delay(5);
  }

  line.trim();
  if (line.length() > 0) {
    Serial.print(context);
    Serial.print(": ");
    Serial.println(line);
    if (line == "OK") {
      return true;
    }
  }

  Serial.print(context);
  Serial.println(": <timeout>");
  return false;
}

bool waitForHttpAction(String& actionLine, uint32_t timeoutMs) {
  const uint32_t deadline = millis() + timeoutMs;
  String line;
  while (millis() < deadline) {
    while (SerialAT.available()) {
      const char c = static_cast<char>(SerialAT.read());
      if (c == '\r') {
        continue;
      }
      if (c == '\n') {
        line.trim();
        if (line.length() > 0) {
          Serial.print("HTTPACTION response: ");
          Serial.println(line);
          if (line.startsWith("+HTTPACTION:")) {
            actionLine = line;
            return true;
          }
          if (line == "ERROR") {
            return false;
          }
          line = "";
        }
      } else {
        line += c;
      }
    }
    delay(5);
  }

  line.trim();
  if (line.startsWith("+HTTPACTION:")) {
    Serial.print("HTTPACTION response: ");
    Serial.println(line);
    actionLine = line;
    return true;
  }

  Serial.println("HTTPACTION response: <timeout>");
  actionLine = "";
  return false;
}

bool sendSimpleAt(const String& command, uint32_t timeoutMs = 5000) {
  drainSerialAt();
  SerialAT.print("AT");
  SerialAT.print(command);
  SerialAT.print("\r\n");
  return waitForOk(timeoutMs);
}

bool sendVerboseAt(const String& command, uint32_t timeoutMs = 5000) {
  Serial.print(">>> AT"); Serial.println(command);
  drainSerialAt();
  SerialAT.print("AT");
  SerialAT.print(command);
  SerialAT.print("\r\n");
  return waitForOkVerbose(timeoutMs, "    ");
}

// AT+CASEND's completion signal varies by modem firmware revision: some return
// an async "+CASEND:" URC, this SIM7000G (R1529) just returns plain "OK" and
// signals incoming data separately via "+CADATAIND:". Accept either as success
// so the upload doesn't hang waiting for a URC this firmware never sends.
bool waitForCasendComplete(uint32_t timeoutMs) {
  const uint32_t deadline = millis() + timeoutMs;
  String line;
  while (millis() < deadline) {
    while (SerialAT.available()) {
      const char c = static_cast<char>(SerialAT.read());
      if (c == '\r') continue;
      if (c == '\n') {
        line.trim();
        if (line.length() > 0) {
          if (line == "OK" || line.indexOf("+CASEND:") >= 0) return true;
          if (line == "ERROR") return false;
          line = "";
        }
      } else {
        line += c;
      }
    }
    delay(5);
  }
  return false;
}

// AT+CARECV's response is "+CARECV: <len>,<raw bytes...>" — the payload that
// follows the prefix is NOT line-oriented text; it's the literal socket data
// (HTTP headers + binary body for an OTA download), which routinely contains
// '\n' bytes of its own. Reading it with a line-based parser silently
// truncates/corrupts chunks at the first embedded newline. Parse the "+CARECV:
// <len>," prefix as a raw byte sequence, then read exactly <len> bytes after
// it — no line semantics involved. Returns bytes copied into buf, or -1 on
// timeout/protocol mismatch (no trailing comma).
int readCarecvChunk(uint8_t* buf, int bufCap, uint32_t timeoutMs) {
  const uint32_t deadline = millis() + timeoutMs;
  const char* needle = "+CARECV: ";
  const int needleLen = 9;
  int matched = 0;
  while (millis() < deadline && matched < needleLen) {
    if (SerialAT.available()) {
      const char c = static_cast<char>(SerialAT.read());
      if (c == needle[matched]) matched++;
      else matched = (c == needle[0]) ? 1 : 0;
    } else {
      delay(1);
    }
  }
  if (matched != needleLen) return -1;

  int len = 0;
  bool sawDigit = false;
  bool sawComma = false;
  while (millis() < deadline && !sawComma) {
    if (SerialAT.available()) {
      const char c = static_cast<char>(SerialAT.read());
      if (c >= '0' && c <= '9') { len = len * 10 + (c - '0'); sawDigit = true; }
      else if (c == ',') sawComma = true;
    } else {
      delay(1);
    }
  }
  if (!sawDigit || !sawComma) return -1;
  if (len > bufCap) len = bufCap;

  int got = 0;
  while (got < len && millis() < deadline) {
    if (SerialAT.available()) buf[got++] = (uint8_t)SerialAT.read();
    else delay(1);
  }
  waitForOk(2000);
  return got;
}
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
void loop() {
  g_loopBeat++;  // feed the hardware loop watchdog (reboots if this stops advancing)
  CRUMB("maintainGps");
  maintainGps();

  const uint32_t nowMs = millis();

  // Recovery is driven by consecutive POST failures below (interval-agnostic, so it
  // never fights the long parked-heartbeat interval the way a fixed-time watchdog did).

  // Refresh BLE device-info characteristic with latest battery reading every 30s.
  static uint32_t lastBleUpdateMs = 0;
  if (nowMs - lastBleUpdateMs >= 30000UL) {
    lastBleUpdateMs = nowMs;
    updateBleDevInfo();
  }

  // Driver-presence: advertise over BLE while on a trip with a GPS fix so the
  // driver's phone can identify this vehicle (see updatePresenceAdvertising).
  updatePresenceAdvertising(ignitionOn && lastGpsFix);

  // Optional add-ons: cooperative CAN state machine (never blocks — one
  // request in flight, drained by polling). The accelerometer runs in its own
  // task and needs no loop service.
  canObd2Service(ignitionOn);

  // Unadopted boards must stay claimable: a WiFi scan (no-fix geolocation
  // fallback) silently kills BLE advertising and nothing re-arms it — bench
  // board advertised after every boot, went dark within minutes indoors, and
  // Add Device found nothing. Re-assert every 30s; a no-op while advertising
  // is already active.
  static uint32_t lastClaimAdvMs = 0;
  if (!g_adopted && g_presenceBleInited && millis() - lastClaimAdvMs >= 30000UL) {
    lastClaimAdvMs = millis();
    updateBleDevInfo();
    BLEDevice::startAdvertising();
  }

  // Evict centrals that connect and never leave: while a phone holds the GATT
  // link the tracker does not advertise AT ALL, so a leaky client silences it
  // for every scanner (field: a phone's stuck connection hid a bench board
  // for a day). Devinfo reads take ~2s; 45s means the other end leaked.
  if (g_bleConnectedAtMs != 0 && g_bleServer && millis() - g_bleConnectedAtMs >= 45000UL) {
    Serial.println("BLE: dropping stale central connection");
    g_bleServer->disconnect(g_bleConnId);
    g_bleConnectedAtMs = 0;
  }

  // Wake-on-motion: while parked the telemetry interval stretches to a 10-min
  // heartbeat. There's no alternator-voltage signal on this hardware, so poll GPS
  // speed directly every 15s; when the vehicle starts moving, jump straight to live
  // tracking instead of waiting out the heartbeat.
  static uint32_t lastWakeCheckMs = 0;
  if (!ignitionOn && nowMs - lastWakeCheckMs >= 15000UL) {
    lastWakeCheckMs = nowMs;
    CRUMB("wakeMotion");
    float wlat = NAN, wlon = NAN, wspd = NAN;
    if (modem.getGPS(&wlat, &wlon, &wspd) && !isnan(wspd) &&
        wspd >= TRACKER_MIN_MOVING_SPEED_KPH) {
      Serial.println("Motion detected while parked — waking to live tracking");
      ignitionOn = true;
      lastMovingMs = millis();
      ignitionOffSinceMs = 0;
      lastTelemetryMs = 0;  // post immediately
    }
  }

  // Instant-event path: a crash candidate or a fresh trouble code posts NOW —
  // event → phone in seconds, not at the next cadence tick.
  float crashG = 0;
  if (accelTakeCrashEvent(&crashG)) {
    Serial.printf("ACCEL: crash candidate %.1f g — posting immediately\n", crashG);
    g_crashReportG = crashG;
    lastTelemetryMs = 0;
  }
  bool instantEvent = g_crashReportG > 0;
  if (canObd2TakeNewDtcEvent()) {
    Serial.println("OBD2: DTC set changed — posting immediately");
    instantEvent = true;
    lastTelemetryMs = 0;
  }

  // While posts are failing, retry fast — don't wait out a long parked-heartbeat
  // interval. When healthy, use the normal adaptive interval.
  const uint32_t interval = (g_consecutivePostFails > 0) ? 15000UL : nextIntervalMs();
  if (lastTelemetryMs == 0 || nowMs - lastTelemetryMs >= interval) {
    lastTelemetryMs = nowMs;
    CRUMB("buildTelem");
    // UDP builds send the compact payload (508-byte datagram limit); the full payload
    // still goes out with every HTTPS heartbeat inside postTelemetry().
    const String payload = buildTelemetry(TRACKER_USE_NCE_UDP != 0);
    g_crashReportG = 0;  // baked into `payload` now; a failed post keeps it via the queue

    // A parked↔moving change is the report the map can't afford to lose —
    // route it over reliable HTTPS instead of fire-and-forget UDP. Crash and
    // fresh-DTC events even more so.
    static char lastSentMotion[12] = "";
    const bool motionChanged =
        lastSentMotion[0] != '\0' && strcmp(lastSentMotion, g_lastBuiltMotion) != 0;

    Serial.println(payload);
    CRUMB("postJson");
    const bool posted = postTelemetry(payload, motionChanged || instantEvent);
    if (posted) strlcpy(lastSentMotion, g_lastBuiltMotion, sizeof(lastSentMotion));
    if (!posted) {
      Serial.println("Queueing telemetry");
      enqueue(payload);
      g_consecutivePostFails++;
      // Escalating recovery — fastest action first. postJson already retries the SSL
      // socket internally, so reaching here means a real outage (dead PDP context, lost
      // registration, or a wedged modem). Each step does what a human would, ending in
      // the full restart that the field symptom needs — but automatically.
      if (g_consecutivePostFails == 3) {
        Serial.println("3 fails — fresh GPRS session");
        g_forcedReconnects++;
        modem.gprsDisconnect();
        gprsConnected = false;
        delay(500);
      } else if (g_consecutivePostFails == 8) {
        Serial.println("8 fails — power-cycling modem");
        g_watchdogCount++;
        modem.gprsDisconnect();
        delay(1000);
        powerOnModem();
        delay(5000);
        waitForModem();
        gpsEnabled = false;  // modem restart resets GNSS
        modem.gprsConnect(TRACKER_APN_PRIMARY, TRACKER_GPRS_USER, TRACKER_GPRS_PASS);
        gprsConnected = modem.isGprsConnected();
      } else if (g_consecutivePostFails >= 15) {
        Serial.println("15 fails — full reboot to recover (auto-restart)");
        delay(200);
        ESP.restart();
      }
    } else {
      lastPostSuccessMs = millis();
      g_consecutivePostFails = 0;
      CRUMB("flushQueue");
      flushQueue();
#if !TRACKER_USE_NCE_UDP
      // Every-5-posts OTA GET = a fresh TLS handshake every ~50s while driving — a big
      // slice of the SIM data burn. UDP builds get OTA offers in the HTTPS heartbeat
      // response instead (handleTelemetryResponse), so they skip this entirely.
      telemetryCycleCount++;
      if (telemetryCycleCount >= 5) {
        telemetryCycleCount = 0;
        CRUMB("otaCheck");
        checkOtaStandalone();
      }
#endif
    }
  }

  CRUMB("idle");
  delay(250);
}
#endif  // GPS_ISOLATION_TEST

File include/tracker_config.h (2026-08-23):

#pragma once

// Cellular SIM settings. Many IoT SIMs use an empty user/password.
#define TRACKER_APN_PRIMARY "iot.1nce.net"
#define TRACKER_APN_FALLBACK "iot.1nce.net"
#define TRACKER_GPRS_USER ""
#define TRACKER_GPRS_PASS ""

#define TRACKER_SERVER_HOST "123mobiletrack.com"
#define TRACKER_SERVER_HOST_HEADER "123mobiletrack.com"
#define TRACKER_SERVER_PORT 443
#define TRACKER_SERVER_PATH "/api/fleet/telemetry"
#define TRACKER_SERVER_URL "https://123mobiletrack.com/api/fleet/telemetry?k=c5cc56a23546eb487223fe810ae8a8b76d83376ee09140f7"

// These can be overridden via build flags (-D) in platformio.ini per environment.
// The default is deliberately "unprovisioned": a board flashed without explicit
// -D flags names itself tracker-<last 6 hex of its efuse MAC> on first boot
// (factory flow) instead of silently impersonating a fleet unit. The fleet
// tracker-001/002/003 envs pass their IDs via build flags.
#ifndef TRACKER_DEVICE_ID
#define TRACKER_DEVICE_ID "unprovisioned"
#endif
#ifndef TRACKER_API_KEY
#define TRACKER_API_KEY "c5cc56a23546eb487223fe810ae8a8b76d83376ee09140f7"
#endif
#define TRACKER_FIRMWARE_VERSION "0.11.14"

// VESTIGIAL: alternator-voltage ignition detection. This hardware uses a 12V→5V buck
// with no voltage sense, and AT+CBC only reads the buffer LiPo (~3.8V), so these can
// never be reached. Trip state is now derived from GPS motion (see TRACKER_TRIP_GRACE_MS).
// Kept only for reference; safe to delete.
#define TRACKER_IGNITION_ON_MV  13200U
#define TRACKER_IGNITION_OFF_MV 12800U

// Tuning knobs.
#define TRACKER_MOVING_INTERVAL_MS 10000UL
#define TRACKER_PARKED_INTERVAL_MS 120000UL
#define TRACKER_MIN_MOVING_SPEED_KPH 3.0f
// How long after the last GPS motion we still treat the vehicle as "on a trip", so a
// red light / stop-and-go doesn't immediately collapse to the slow parked cadence.
#define TRACKER_TRIP_GRACE_MS 180000UL
// Harsh-event detection from GPS speed. The OLD logic flagged any absolute speed
// change over a window up to EVENT_WINDOW_MS, so a gentle 22 kph slowdown spread
// over 12 s tripped the SAME alert as a genuinely abrupt one — far too many false
// "hard brake" alerts. Now we threshold on the deceleration RATE (kph per second,
// normalised by the actual sample gap) and also require a minimum absolute change
// so one noisy GPS sample can't trip it. NOTE: with GPS speed only sampled every
// ~10 s these are still coarse; true harshness needs an IMU or high-rate sampling.
// Thresholds are calibrated to industry telematics defaults (Geotab passenger:
// -9.13 kph/s brake, 8.05 kph/s accel ≈ 0.25g). The old -4.0/5.0 (≈0.11g) was
// hair-trigger: ordinary firm braking at a yellow light scored as "harsh" and
// buried the scorecard in noise.
#define TRACKER_HARD_BRAKE_RATE_KPH_S  -9.0f    // <= this rate (kph/s) = hard brake (~0.25g)
#define TRACKER_RAPID_ACCEL_RATE_KPH_S  8.0f    // >= this rate (kph/s) = rapid accel (~0.23g)
#define TRACKER_EVENT_MIN_DELTA_KPH     15.0f   // ignore speed changes smaller than this
#define TRACKER_EVENT_MIN_DT_MS         2000UL  // gaps shorter than this = GPS jitter
#define TRACKER_EVENT_WINDOW_MS         12000UL // gaps longer than this aren't one event
// TLS connect timeout (seconds). TinyGSM defaults to 75s with no override, so a wedged
// SIM7000G CAOPEN can stall the whole loop long enough to hit the 180s loop watchdog
// (field freeze: last_hang_op="tlsConnect"). Bound it short so a bad connect fails fast
// and hands off to the escalating post-fail recovery instead of hanging.
#define TRACKER_TLS_CONNECT_TIMEOUT_S 20
// Use the SIM7000G's native HTTP(S) app (AT+SHREQ) for telemetry POSTs instead of raw
// TLS sockets, which drop ~half of HTTPS responses at this cadence (a documented modem
// limit). The native path is the primary; postJson() auto-falls-back to the raw-TLS
// path and self-disables native after repeated failures, so an unsupported/buggy modem
// firmware can never take the fleet dark. Set to 0 to force the old raw-TLS path.
#define TRACKER_USE_NATIVE_HTTPS 1
// 1NCE OS UDP transport. Telemetry goes as a single plain-UDP datagram to the 1NCE
// endpoint inside the carrier network (the SIM is the identity — no TLS on the device);
// 1NCE forwards it to /api/fleet/nce-webhook over HTTPS. Kills the per-post TLS
// handshake (~6-9KB each) that was burning the SIM data budget. A full HTTPS POST
// still runs every TRACKER_NCE_HTTPS_HEARTBEAT_MS for assured delivery + OTA offers,
// and every UDP failure falls back to HTTPS, so the tracker→server→map pipeline can
// never go dark from the UDP path alone. Fleet default ON as of v0.10.1 — proven
// end-to-end on the bench (tracker-001, 2026-07-05). NOTE: a SIM whose data session
// predates the org's 1NCE OS activation isn't routed to the UDP endpoint until it
// re-attaches (fix: Reset connection in the portal / POST /v1/sims/{iccid}/reset);
// the HTTPS fallback covers tracking either way. Set 0 to force HTTPS-only.
#ifndef TRACKER_USE_NCE_UDP
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

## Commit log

2026-06-13 Checkpoint: GPS diagnostic state (v0.9.17, isolation test mode)
    Documents the current experimental firmware while chasing the GPS-no-lock issue.
    KEY FINDING vs original (commit ca563e2, v0.1.0): the original ensureGps() was
    just `modem.enableGPS()` — ZERO GNSS config commands. This tree added 25
    PMTK/CGNSMOD/CVAUXS/CGNSCMD/AGPS/injectSavedPosition calls, none of which were
    in the working version. Prime suspect for the GPS regression.
    Current state: GPS_ISOLATION_TEST=1 (cellular dropped, GNSS streamed to serial).
    Confirmed: chip reports 0 sats / empty C/N0 outdoors across every config tried.
    Also changed from original: default partition -> min_spiffs.csv (for BLE), which
    wiped GPS warm-st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
    [165-water-deck-final-underlay.skp, 165-water-deck-fixed-underlay.skp, 165-water-deck-underlay.skp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]
2026-06-14 GPS: fix no-lock death spiral — stop wiping ephemeris on every enable
    ensureGps() ran $PMTK104 (full cold start; wipes ephemeris/EPO/position) on
    every enable, and setup() pulled AGPS before powering GNSS, so the EPO was
    discarded right after download -> perpetual cold start. CGNSMOD=1,1,1,1 also
    conflicted with PMTK353 (GPS+GLONASS+BeiDou).
    - Gate $PMTK104 behind one-shot NVS flag (gnss/factory_reset); never routine
    - setup(): ensureGps() before downloadAgps() so AT+CAGPS injects into a live engine
    - CGNSMOD=1,1,0,0 + PMTK353,1,1,0,0,0 (GPS+GLONASS)
    - Drop contradictory post-reset $PMTK101
    - Disable GPS_ISOLATION_TEST (normal telemetry posting); bump 0.9.17 -> 0.9.18
    Validated on tracke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
    [main.cpp, tracker_config.h]
2026-06-14 GPS: power the active antenna (AT+CGPIO=0,48,1,1) — THE no-lock root cause
    The T-SIM7000G gates active-antenna LNA bias behind modem GPIO4. The firmware
    sent AT+CVAUXS=1 (wrong command; returns ERROR), so the active antennas were
    never powered -> 0 satellites on every board. An unpowered active LNA blocks
    the signal. Replaced with AT+CGPIO=0,48,1,1.
    Verified on a fresh board + active antenna in open sky: FIX in 7s, 21 sats in
    view, C/N0 52 dB-Hz, 41.2335,-73.1292. (Unpowered active = 0 sats; passive in
    poor sky = 1 sat.) This is the actual root cause of the long-standing no-lock.
    Bump 0.9.18 -> 0.9.19.
    [main.cpp, tracker_config.h]
2026-06-16 Fix mid-drive modem sleep + GPS dead after watchdog (v0.9.20)
    Two field-reported bugs on the LilyGo T-SIM7000G trackers:
    1. Tracker goes to sleep mid-drive and stops sending heartbeats.
    The SIM7000G / 1NCE network could negotiate PSM and UART sleep,
    making the modem unreachable. waitForModem() now disables both on
    every modem bring-up (boot AND watchdog restart):
    AT+CSCLK=0 (UART sleep off)
    AT+CPSMS=0 (network power-saving mode off)
    2. GPS stayed dead after the POST watchdog power-cycled the modem.
    The watchdog reset the modem but left gpsEnabled=true, so
    ensureGps() short-circuited and never re-initialized GNSS. Now the
    watchdog clears gpsEnabled so GNSS re-i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
    [main.cpp, tracker_config.h]
2026-06-16 Fix build: forward-declare sendSimpleAt before waitForModem
    The v0.9.20 sleep fix called sendSimpleAt() inside waitForModem(), but
    sendSimpleAt is defined later in the file — compile error ('not declared
    in this scope'). Add a forward declaration. Verified: builds clean and
    flashed to tracker-002 successfully.
    [main.cpp]
2026-06-18 Fix telemetry stalls: fresh connection per POST (v0.9.22)
    Diagnosed live on tracker-002 serial: every OTHER telemetry POST got
    "no response", hung for the full 15s read timeout, and re-queued — the
    queue climbed and, while driving (fast interval + cell handovers), this
    cascaded into multi-minute stalls and tripped the 3-min POST watchdog.
    Root cause: postJson reused the kept-alive TLS socket, but the server had
    already closed it after the previous response, so the reused request went
    nowhere. A FRESH connection always returned 200 OK.
    Fix: secureClient.stop() after every POST so each one opens a fresh socket.
    Kept Connection: keep-alive (NOT close) — the SIM7000G drops the RX buffer
    if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
    [main.cpp, tracker_config.h]
2026-06-20 Self-healing recovery + diagnostics; document SIM7000G SSL limit (v0.9.26)
    Field report: tracker freezes mid-drive and only a full restart resumes it
    (a modem-only power-cycle didn't). Long serial captures + 10 direct timed
    POSTs to the server pinned the cause: the SERVER is fast/reliable (<1.5s,
    HTTP/2, supports keep-alive), but the SIM7000G's RAW TLS sockets silently
    drop ~half of HTTPS responses in clustered 20-60s windows. Measured and ruled
    out every connection strategy — fresh-per-post, settle delays, 3x retry, and
    persistent reuse all gave ~50%. This is a known limitation of the module's
    CAOPEN/CARECV SSL path; the real fix is the modem's native HTTPS client
    (AT+SHREQ), tracked sepa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
    [main.cpp, tracker_config.h]
2026-06-21 Fix GNSS stuck-off: re-kick when engine reports OFF (v0.9.27)
    Field test (good antenna, clear sky) showed 0 sats for 4.5 min: CGNSINF run
    status stuck at 0 (engine off) while the firmware believed gpsEnabled=true.
    Root cause: modem.enableGPS() returns true as soon as the modem ACCEPTS
    CGNSPWR=1, but on the SIM7000G the engine often doesn't actually start after a
    modem power-cycle. ensureGps() then early-returns on gpsEnabled forever, and
    maintainGps() only recycles after 30 min of NO FIX (not engine-off) — so GNSS
    was stuck off with nothing re-kicking it.
    Fix: maintainGps() now parses the CGNSINF run-status field. If the engine
    reports OFF while enabled for ~60s (2 status logs), it re-ki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
    [main.cpp, tracker_config.h]
2026-06-21 Fix mid-drive freeze: it was a HUNG LOOP, not a posting failure (v0.9.28)
    Field freeze diagnosed from the server diagnostics: tracker stopped posting
    38 min mid-drive while MOVING WITH A FIX, yet watchdog_count=0,
    forced_reconnects=0, and it never rebooted. The escalating recovery only runs
    when postJson() RETURNS — so a loop stuck inside a blocking call (never returns)
    gets no recovery and no reboot. That's why none of the prior recovery work
    saved it.
    The only call that can hang INDEFINITELY (everything else has a timeout) is
    WiFi.scanNetworks(), which ran every 5 min — including while driving with a
    fix, where WiFi geolocation isn't even needed.
    Two-layer fix:
    1. Skip the WiFi scan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
    [main.cpp, tracker_config.h]
2026-06-21 Make WiFi scan un-hangable: async + 8s timeout (v0.9.29)
    v0.9.28's hardware watchdog DID catch the mid-drive freeze (field drive:
    boot_count climbed by ~2, watchdog_count/forced_reconnects stayed 0 = loop
    hangs that self-recovered via reboot). But the WiFi scan could still hang
    during GPS-less windows (re-acquiring after a reboot, or a tunnel), causing
    repeated reboots across a drive.
    Root fix: scanWifi() now uses an ASYNC scan (WiFi.scanNetworks(true)) and polls
    WiFi.scanComplete() with an 8s deadline, abandoning if it doesn't finish — so a
    wedged WiFi stack can never block the loop. Feeds the loop watchdog while
    waiting. Combined with the fix-gating (skip scan when GPS has a fix) and th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
    [main.cpp, tracker_config.h]
2026-06-22 Add hang breadcrumb + reset-reason diagnostics; shorten net wait (v0.9.31)
    Field drive on v0.9.30: still froze "a handful of times", but the hardware
    watchdog caught each one (boot_count climbed ~4, watchdog_count=1,
    forced_reconnects=1) and self-recovered — no more permanent dead-stops. But
    the watchdog doesn't log WHERE it hung now that the WiFi scan is async.
    So: a breadcrumb in RTC_NOINIT memory (survives a software/watchdog reset)
    records the operation currently running; on the next boot we read it back
    along with esp_reset_reason() and report both in telemetry as `last_hang_op`
    and `reset_reason`. Crumbs at every blocking phase: maintainGps, buildTelem,
    wifiScan, cellInfo, waitNet,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
    [main.cpp, tracker_config.h]
2026-06-28 Fix mid-drive freeze (tlsConnect hang) + rate-based hard-brake + GPS-motion ignition (v0.9.32)
    Freeze: field unit tracker-001 reported reset_reason=sw(watchdog),
    last_hang_op="tlsConnect" — the v0.9.28 WiFi-scan fix worked and the hang
    relocated to the TLS connect. TinyGSM's connect() defaults to a 75s timeout
    (no override), so a wedged SIM7000G CAOPEN stalls the loop into the 180s
    watchdog reboot (= the perceived ~3-min mid-drive freeze). Bound it:
    secureClient.connect(host, port, TRACKER_TLS_CONNECT_TIMEOUT_S=20) so a bad
    connect fails fast and hands off to the escalating post-fail recovery.
    Hard brake: old logic flagged any absolute >=22 kph drop over a window up to
    12s, so a gentle 12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
    [main.cpp, tracker_config.h]
2026-06-28 Native HTTPS POST via SIM7000G AT+SHREQ, with raw-TLS fallback (v0.9.33)
    The raw TLS sockets drop ~half of HTTPS responses at this cadence (documented
    SIM7000G limit). Add postJsonNative() using the modem's built-in HTTP(S) app
    (SHCONF/SHCONN/SHAHEAD/SHBOD/SHREQ/SHREAD/SHDISC) as the primary telemetry path.
    Safety: postJson() now dispatches native-first and transparently falls back to
    the existing raw-TLS path on any failure; after 3 consecutive native failures it
    latches native OFF until reboot, so a modem firmware that doesn't support SHREQ
    (or a wrong SHBOD form) can never take the fleet dark. Toggle with
    TRACKER_USE_NATIVE_HTTPS. Response handling (OTA offer + WiFi-geo fix) factored
    int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
    [main.cpp, tracker_config.h]
2026-06-29 Fix OTA download: CASEND completion signal + binary-unsafe CARECV parsing (v0.9.39)
    Two real bugs found via live OTA testing against tracker-002, both stemming
    from this SIM7000G's firmware (R1529) behaving differently than the original
    code assumed:
    1. AT+CASEND completion: code waited for an async "+CASEND:" URC that this
    modem firmware never sends — it returns plain "OK" instead, followed by a
    separate "+CADATAIND:" once response data arrives. Added
    waitForCasendComplete() to accept either, used by both the OTA download
    and the provisioning cellularRequest() path (same bug, same fix).
    2. AT+CARECV parsing: the response is "+CARECV: <len>,<raw bytes>" where the
    raw bytes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
    [main.cpp, tracker_config.h]
2026-07-02 Fix OTA: chunked decoder, watchdog feed, content-length completion (v0.9.47)
    Four OTA download bugs fixed:
    - waitForCasendComplete: accept "OK" in addition to "+CASEND:" URC (R1529 never
    sends the URC — it just returns OK then fires +CADATAIND)
    - readCarecvChunk: binary-safe byte-exact parser instead of text line reader;
    AT+CARECV data contains embedded \\n bytes that truncated every chunk
    - ChunkedOtaDecoder: HTTP chunked transfer-encoding state machine; the raw HTTP
    body includes chunk-size lines that were being written to flash verbatim
    - Body loop: use Update.progress() >= contentLength as completion signal instead
    of waiting for the terminal 0\\r\\n\\r\\n chunk (TCP half-close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
    [main.cpp, tracker_config.h]
2026-07-03 v0.9.48 — known-good fleet firmware (fallback baseline)
    Version bump only; source identical to v0.9.47 (commit 78eaa13). This is the
    exact build running on tracker-002: OTA'd successfully over cellular, reports
    telemetry, holds a GPS fix, and logged a real 36 km / 42 min trip end-to-end
    (2026-07-02). Tagged as the safe rollback point — if a future firmware misbehaves
    in the field, flash/OTA back to this.
    [tracker_config.h]
2026-07-05 v0.10.0 — 1NCE OS UDP transport, bench trial on tracker-001
    Telemetry goes as one plain UDP datagram (~280B) to udp.os.1nce.com:4445
    inside the carrier network — no TLS handshake on the device. Root cause of
    the SIM data burn was ~430 TLS handshakes/hour while driving: SHCONN per
    post + a standalone OTA GET every 5 posts (~3.5MB/h vs ~4MB/month budget).
    - postUdp1nce(): CA-app UDP on cid 0 (CASSLCFG protocol,1 + 3-arg CAOPEN,
    5-arg fallback); restores TCP protocol for the TLS/OTA paths after use
    - postTelemetry() dispatcher: full-payload HTTPS heartbeat every 15 min
    (assured delivery + OTA offer in response), UDP between heartbeats,
    automatic HTTPS fallback when UDP can't send or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
    [main.cpp, tracker_config.h]
2026-07-05 v0.10.1 — 1NCE UDP transport fleet default ON; published to OTA
    Bench (tracker-001) proved the full path: UDP datagram → 1NCE Device
    Integrator → Cloud Integrator webhook → /api/fleet/nce-webhook →
    telemetry_latest (transport=nce-udp rows at seeking-fix cadence).
    Root cause of earlier silence: data sessions established before the
    org's 1NCE OS activation aren't routed to the UDP endpoint — fixed by
    a connectivity reset (POST /v1/sims/{iccid}/reset). Van (tracker-002,
    SIM ...369, the data burner) picks this up via OTA on next check-in.
    [tracker_config.h]
2026-07-06 v0.10.2 — motion transitions post via reliable HTTPS, not UDP
    A lost fire-and-forget datagram at a parked→moving edge left the map
    showing the wrong state until the next packet landed. Transitions are
    rare and important: route them through postJson (retried + queued),
    keep steady-state reports on UDP. Server side pairs with an
    out-of-order-datagram guard in telemetry.ts.
    [main.cpp, tracker_config.h]
2026-07-06 v0.10.3 — UDP DNS/IP fallback, server-driven blackhole latch; fix phantom OTA publishes
    Field failures after truck install: 1NCE stopped routing the SIM's new
    session to the UDP endpoint (2nd occurrence in 24h) and every datagram
    died silently while the device believed sends succeeded.
    - CAOPEN tries udp.os.1nce.com then the known 1NCE-internal IPs
    (10.60.2.239 / 10.60.8.90) — covers per-session modem DNS failures
    - Heartbeat responses now carry udp_age_s (server-side time since a
    datagram last ARRIVED); if the device sent ≥5 since the last heartbeat
    and none landed, it latches HTTPS-only for 60 min — a 1NCE routing
    failure can no longer stale the map
    - udp_fail_streak / udp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
    [main.cpp, tracker_config.h]
2026-07-11 v0.10.4 — driver-presence BLE advertising while on a trip with a fix
    Provisioned trackers now advertise the fleet GATT service while ignitionOn &&
    lastGpsFix, so the iOS app (build 48+) can hear which vehicle the driver is
    physically in and report presence — no location sharing needed.
    The setup-only BLE restriction existed because BLE breaks WiFi.scanNetworks();
    WiFi-shortcut geolocation only runs when there's NO fix, so gating advertising
    on a fix preserves that fallback: fix lost or trip over → advertising stops.
    BLE stack inits once on first trip (bluedroid deinit is unreliable); the
    existing 30s devinfo refresh keeps battery/fw current for the app's read.
    Published to OTA (verif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
    [main.cpp, tracker_config.h]
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2026-07-12 v0.10.6 — re-advertise BLE after a central disconnects (bench-found)
    The stack stops advertising when a phone connects to read devinfo and
    never resumes it, so one background read (e.g. the app's presence
    watcher) made a tracker permanently invisible — Add Device found
    nothing on the bench because the owner's phone had already connected.
    Server callback now restarts advertising on disconnect while the board
    is unadopted (claim mode) or presence advertising is on. Also fixes
    degraded driver-presence detection after the first devinfo read.
    Verified on bench board tracker-123c40 (identity survived reflash).
    [fleet_inventory.csv]
2026-07-14 v0.10.7 — keep unadopted boards claimable: re-assert BLE advertising every 30s
    Root cause of 'phone can't see the tracker' (after the app-side scan
    fixes in builds 49/50): the no-fix WiFi-scan geolocation fallback
    silently kills BLE advertising on the shared 2.4GHz radio and nothing
    re-arms it. The board advertised for the first minute after every
    boot (which is why every bench reset 'fixed' it briefly) and then went
    permanently dark indoors. While unadopted, the loop now re-asserts
    advertising every 30s (a no-op when already active), so the board is
    claimable no matter what the radio has been through.
    Bench-verified on tracker-123c40: 4+ min uptime, 60s continuous
    advertising, zero gaps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
    [main.cpp, tracker_config.h]
2026-07-14 v0.10.8 — evict stale BLE centrals so a leaky phone can't silence the tracker
    While a central holds the GATT link the tracker does not advertise at
    all — a phone-app connection leak kept a bench board invisible to
    every scanner for a day, discoverable only as 'Connected: 123Track' in
    the phone's Bluetooth settings. Devinfo reads take ~2s; any connection
    held 45s is a bug on the client end, so the server now stamps
    connections (onConnect) and the loop drops them at 45s, after which
    onDisconnect re-arms advertising as usual. Companion app-side fix
    (always disconnect in finally) ships in iOS build 52.
    [fleet_inventory.csv]
2026-07-14 v0.10.9 — identity in the advertised BLE name; no connection needed to identify
    The GATT devinfo read hangs indefinitely on iOS against bluedroid
    (works from macOS): the app's claim scan FOUND and CONNECTED to boards
    — the stuck connection visible in iOS Bluetooth settings — then
    reported 'no trackers found' when the read never returned. Rather than
    keep fighting that stack interaction, the identity now rides in the
    advertised name ('123T-<id suffix>'), so phones identify trackers
    straight from the advertisement: nothing to connect, hang, or leak.
    The devinfo characteristic remains for richer reads. Companion app
    change (name-based matching, bounded legacy reads) ships in build 53.
    Co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
    [main.cpp, tracker_config.h]
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2026-07-15 v0.11.1 — listen-before-transmit CAN probing
    Field incident: plugging the (unpowered, still-terminated) CAN tap
    into a live vehicle bumped the idle and latched a 'service power
    steering' warning — a live automotive bus tolerates zero abuse. The
    probe now starts in TWAI LISTEN_ONLY mode, which is physically passive
    (no TX, no ACK bits), and only switches to normal mode for OBD2
    requests after hearing ≥20 healthy frames at 500k. A silent or
    wrong-bitrate bus is never spoken to. Also protects against the
    misconfigured-bitrate case where a normal-mode node corrupts frames
    just by ACKing. Deployment notes: disable the Mini CAN's onboard 120Ω
    terminator before connecting to a vehicle (the b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
    [accel_tamper.cpp, can_obd2.cpp, tracker_config.h]
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2026-07-18 Tune CAN listen phase from live-vehicle testing (2017 Silverado)
    First live session: the listen-locked build heard 5,500+ frames in 90s
    (dash calm — passive tap fully verified), but the production build's
    listen phase expired before promoting: a 5s window needing 20 frames
    doesn't survive this firmware's boot congestion, where modem bring-up
    blocks the loop for seconds and each service pass drains at most one
    RX queue. Now 5 frames (already unambiguous) within 30s, rx queue
    deepened 16→32. Result on the truck: 'bus traffic heard — probing' →
    'bus detected (11-bit)' — first successful two-way OBD2 exchange.
    Also learned: the desk echo self-test fails at 500k with an
    unterminated OB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
    [can_obd2.cpp]
2026-07-18 v0.11.3 — poll OBD PIDs while parked so idling is measurable; re-probe on a timer
    Idle time is engine-on-while-stopped, which is by definition NOT a
    trip — but PID polling was gated on trip state (GPS motion), so the
    engine data went dark during the exact window the fleet features bill
    by. PIDs now poll on any READY bus, at a relaxed 30s/PID cadence while
    parked. Also: bus re-probe is no longer gated on trips either — field
    lesson from an hour of driveway idling where one unlucky boot marked
    the bus absent and never retried. Listen phase is passive, so probing
    a sleeping bus is harmless.
    [can_obd2.cpp, tracker_config.h]
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2026-07-22 v0.11.6 — crash detection with instant-post pipeline
    An impact ≥12 g (TRACKER_CRASH_THRESHOLD_G) is a crash candidate: the
    sampler flags it, the main loop picks it up on the next pass, and the
    telemetry posts IMMEDIATELY over reliable HTTPS — event → server in
    seconds instead of waiting out the cadence. Payload gains event:
    "impact_crash" + crash{peak_g, speed_kph} (last GPS speed before the
    hit; the obd section carries wheel speed).
    Same instant path for trouble codes: a stored-DTC set that changes
    mid-session (vs baseline-only on the first read of a boot) forces an
    immediate reliable post, so check-engine alerts stop waiting for the
    next tick. Mode 04 clear resets the signature.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
    [accel_tamper.cpp, can_obd2.cpp, main.cpp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]
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2026-07-23 v0.11.9 — VIN request retries until captured
    Field bug: the VIN read was one-shot per boot; if the bus wasn't ready
    at that instant (typical — boot races modem bring-up) the tracker ran
    forever with no VIN, so the app's auto-fill + tamper binding never
    armed. Now re-requests every 2 min until all 17 chars land, then stops
    for the boot.
    [can_obd2.cpp, tracker_config.h]
2026-07-23 v0.11.10 — fix the crash-loop chain (boot 50→170 field incident)
    Root cause (confirmed by parallel audit + production data): the 0.11.7
    bus survey pushed full heartbeat payloads past the modem's 1024-byte
    SHBOD cap → every heartbeat rejected → retried on EVERY post with
    multi-second AT stalls → 180s loop watchdog reboot, every few minutes,
    ~120 reboots in a day. No full payload (VIN/diagnostics/reset_reason)
    could reach the server the entire time.
    Fixes:
    - Heartbeat: failed attempts back off 2 min (never per-post); body >1000B
    rebuilds without the survey; survey window 10→6 entries.
    - CRUMB() now feeds the loop watchdog: slow post-crash cell attach in
    setup() no longer chain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
    [can_obd2.cpp, main.cpp, tracker_config.h]
2026-07-24 v0.11.11 — cold-start crank forensics + mechanic-mode fast streaming
    Crank forensics: on each engine-start transition (rpm 0→running), open a
    5s window polling ONLY voltage (0x42) fast and capture the minimum
    (crank/alternator-ramp sag) → doc.crank_v_min (consume-once, one post).
    Server trends it per vehicle; a deepening dip predicts battery death
    before it strands the truck. Honest limit: catches the sag once polling
    starts, not necessarily the deepest starter-motor instant.
    Mechanic mode: telemetry response can carry fast_stream_s (server-set,
    bounded ≤1800s); nextIntervalMs() streams at 1s while the deadline holds,
    so the app's gauges move like a live scan tool, then self-expires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
    [can_obd2.cpp, main.cpp, tracker_config.h]
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2026-07-26 v0.11.13: delivery watchdog — black-holed UDP can no longer look like success
    Field failure: truck parked overnight, 11 straight 10-min beacons swallowed
    (1NCE session not routing UDP AND HTTPS heartbeats failing), zero reboots —
    postUdp1nce() returns true when the datagram is handed to the modem, so
    g_consecutivePostFails stayed 0 and the escalating recovery never engaged.
    The blackhole detector couldn't help: it only learns from a SUCCESSFUL
    heartbeat response, and those were failing too.
    Fix: g_lastServerContactMs is stamped only by a confirmed HTTPS exchange
    (postJson success, both native and raw-TLS paths). If contact goes stale
    (20 min, under the app's 35-min offline cutoff), post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
    [main.cpp, tracker_config.h]
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
